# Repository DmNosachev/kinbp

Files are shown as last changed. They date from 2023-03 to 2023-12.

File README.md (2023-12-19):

# KinBP
KinBP is a drop-in replacement controller for [Kinesis Contoured keyboards](https://deskthority.net/wiki/Kinesis_Contoured).

It serves the same purpose as [KinT controller](https://github.com/kinx-project/kint) created by Michael Stapelberg.

KinBP v1.2

## Features and advantages
- Controller with [QMK firmware](https://qmk.fm/) support.
- Uses inexpensive [WeAct Studio STM32F401/STM32F411](https://github.com/WeActTC/MiniSTM32F4x1) MCU board. The cost of manufacturing 5 sets is about 12 USD per controller. The PCB has dimensions less than 100×100 mm. Many manufacturers provide additional discounts for smaller boards.
- Compatible with all Kinesis Contoured keyboards but the earliest models (100/110/120).
- Additional pads for connecting up to 8 swithes (i.e. additional switches on the keyboard or foot pedals).
- Replacement thumb cluster PCBs with reversible design. They may be needed for some of 13x models (see below). 
- Thumb cluster switch mounting plates.

## Changelog
1.21
- added 7-pin 1.25mm connector footprints (micro JST) for custom thumb cluster PCBs
- added spare footprints upside down for connectors with pins on the other sideю

## BOM
###  Connectors
The choice of connectors depends on the keyboard model:
 - KB600 (Advantage2).
 1. 6x 13-pin FPC connectors. [Molex 39-53-2135](https://octopart.com/39-53-2135-molex-7670149?r=sp).  Please note that the cheap (5 USD for 20 pcs) [connectors from Aliexpress](https://aliexpress.com/item/1005001616368875.html?item_id=1005001616368875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) are polarised and can only be used for the top row connectors on the KB600; using them in the other positions will not work because the pads on the FPC cable are on the wrong side and the cables are too short to be twisted.

 - KB500 (Advantage).
 1. Connecting keywells and top rows: 4x 13-pin FPC connectors, same as mentioned above.
 2. Connecting thumb cluster PCBs: 2x 10-pin angled 2.54mm headers.

 - KB13x (Essential, Classic, Professional).
 1. Connecting keywell PCBs: 2x [angled 13-pin FPC connectors](https://aliexpress.com/item/32896882494.html?item_id=32896882494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).
 2. Connecting top rows: same angled connectors or straight (same as for KB500/KB600).
 3. Some models had LEDs on the thumb cluster PCBs instead of the controller PCB. In this case you will need a pair of new thum cluster PCBs, optional switch mounting plates (see below) and set of cables/connectors with 1.25mm pitch: 2x [7 pin micro JST 10cm cables](https://aliexpress.com/item/4000588750065.html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) + 4x [7 pin micro JST angled connector](https://aliexpress.com/item/4000587245338.html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).
 
 Example of incompatible stock thumb cluster PCBc (Kinesis Professional KB134PC): KB134PC controller
 
 You can also reuse connectors from an stock controller, but desoldering them can be tricky. Please note that the Chinese aliexpress connectors and some of the older connectors only had contacts on one side. For the top rows, you need to position the connector so that the contacts are on the outside (there are two footprints for this): top row connector
 
### Controller PCB (/controller-pcb).
  - [WeAct Studio STM32F401 or STM32F411](https://github.com/WeActTC/MiniSTM32F4x1) board. You can buy them for about 6 USD at the [official Aliexpress store](https://weactstudio.aliexpress.com/). Beware of pirated copies!
  KinBP v1.21
  - 4 pcs 3-mm LEDs
  - 4 pcs 0805 or through-hole resistors. Their value depends on the type of LEDs (I use 1.5k Ohm for orange LEDs).
  - Pair of USB Type C male and female connectors.
###  Thumb cluster (/thumb-pcb)
  - The design is reversible. So, a minimal batch of 5 PCBs will give you 2 pairs + 1 spare.
  Thumb PCB
  Thumb PCB
  - 12x SOD-123 1N4148 diodes.
  - Optional [switch mounting plates](https://github.com/DmNosachev/kin80/tree/main/plates/thumb)
  - set of connectors and cables (see above)
### Switches
  - Optional: 68 pcs Cherry MX compatible switches.
  
## Buid guide
1. Test your keyboard. Identify faulty switches. Decide if you like the switches (most of the time there will Cherry Browns) and the top row rubber buttons. If rubber buttons are unacceptable to you and you do not mind spending a lot of time on hand-wiring, then it is worth considering an alternative project — (Kin80)[https://github.com/DmNosachev/kin80].
2. Disassemble the keyboard. Remove all screws and remove all PCBs. If some of the rubber buttons don't work well, the top row assembly can be taken apart and repaired by sticking pieces of copper tape on the button bottoms. Use hot-melt adhesive to asseble it back.
3. Assemble the controller PCB.
4. Optional: assemble thumb cluster PCBs.
5. Case. Seal the holes on the back of the case with pieces of plastic. Glue the USB connector to the back of the case. Optional: use bitumen sound deadening pads to improve acoustics.
6. [Setup the QMK](https://docs.qmk.fm/).
7. Flash the firmware: `qmk flash -kb kinbp -km default`. Hold 'boot0' button on MCU board, press 'reset', then release 'boot0' to enter bootloader.

## TODO
- FR4 mounting plate for the thumb cluster.
- Create universal or separate PCB with RP2040 support.

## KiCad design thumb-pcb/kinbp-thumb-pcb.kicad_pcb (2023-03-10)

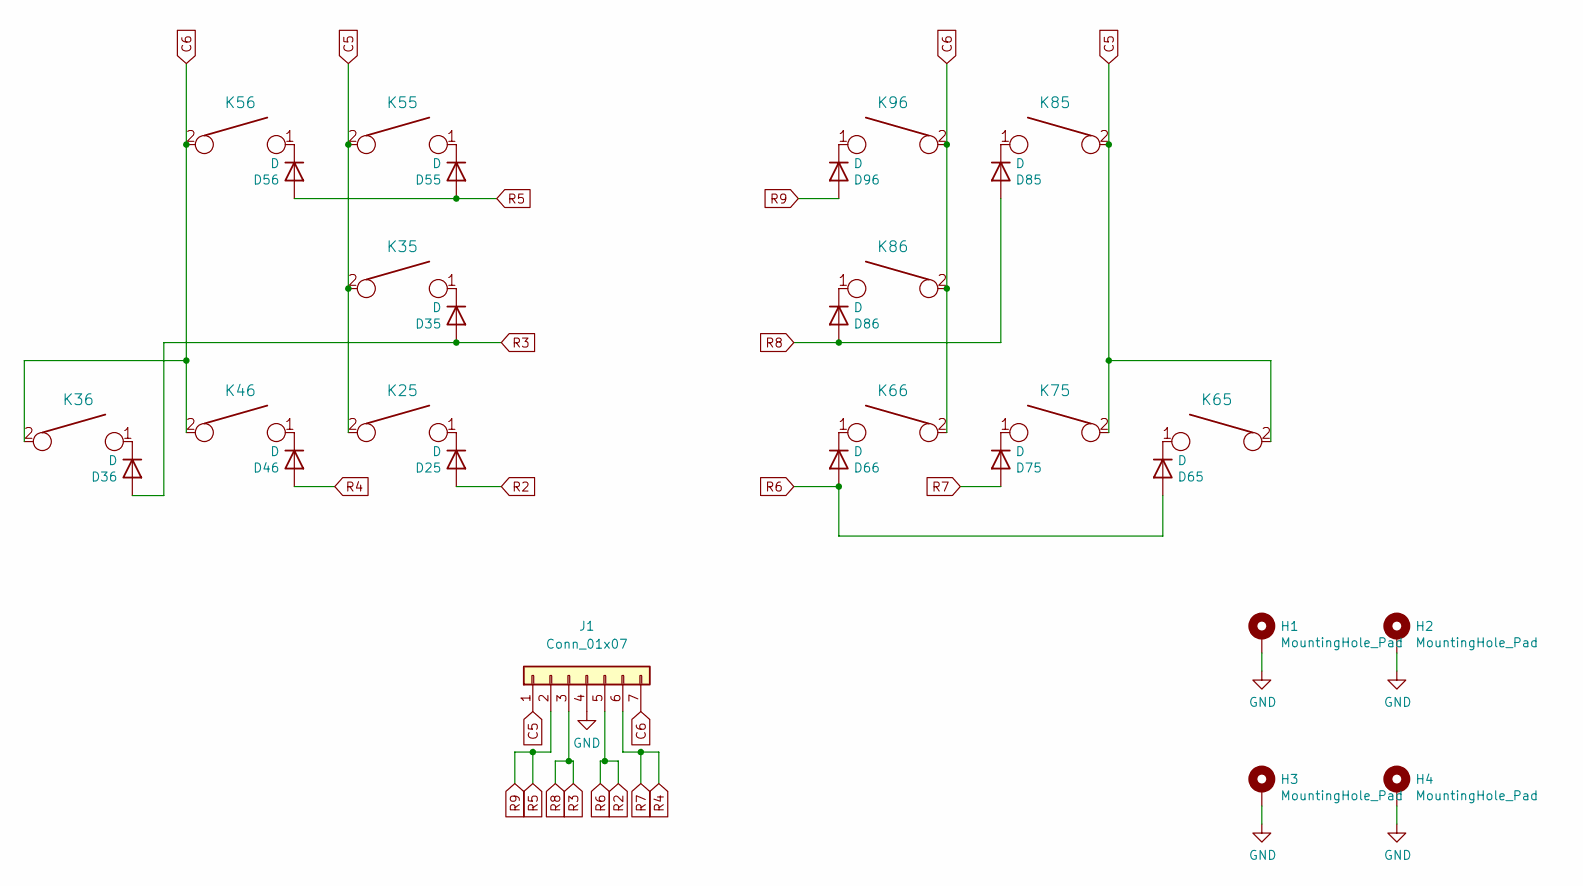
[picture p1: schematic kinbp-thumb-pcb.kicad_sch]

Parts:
D25, D35, D36, D46, D55, D56, D65, D66, D75, D85, D86, D96: D; D_SOD-123
H1, H2, H3, H4: MountingHole_Pad; MountingHole_3.7mm_Pad
J1: Conn_01x07; Molex_PicoBlade_53048-0710_1x07_P1.25mm_Horizontal
K25, K35, K36, K46, K55, K56: KEYSW; MXOnly-1U-NoLED-twin
K65, K66, K75, K85, K86, K96: KEYSW; MXOnly-1U-NoLED

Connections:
C5: J1.1, K25.2, K35.2, K55.2, K65.2, K75.2, K85.2
C6: J1.7, K36.2, K46.2, K56.2, K66.2, K86.2, K96.2
GND: H1.1, H2.1, H3.1, H4.1, J1.4
unnamed: D25.1 (K), K25.1
unnamed: D35.1 (K), K35.1
unnamed: D36.1 (K), K36.1
unnamed: D46.1 (K), K46.1
unnamed: D55.1 (K), K55.1
unnamed: D56.1 (K), K56.1
unnamed: D65.1 (K), K65.1
unnamed: D66.1 (K), K66.1
unnamed: D75.1 (K), K75.1
unnamed: D85.1 (K), K85.1
unnamed: D86.1 (K), K86.1
unnamed: D96.1 (K), K96.1
R2: D25.2 (A), D65.2 (A), D66.2 (A), J1.5
R3: D35.2 (A), D36.2 (A), D85.2 (A), D86.2 (A), J1.3
R4: D46.2 (A), D75.2 (A), J1.6
R5: D55.2 (A), D56.2 (A), D96.2 (A), J1.2

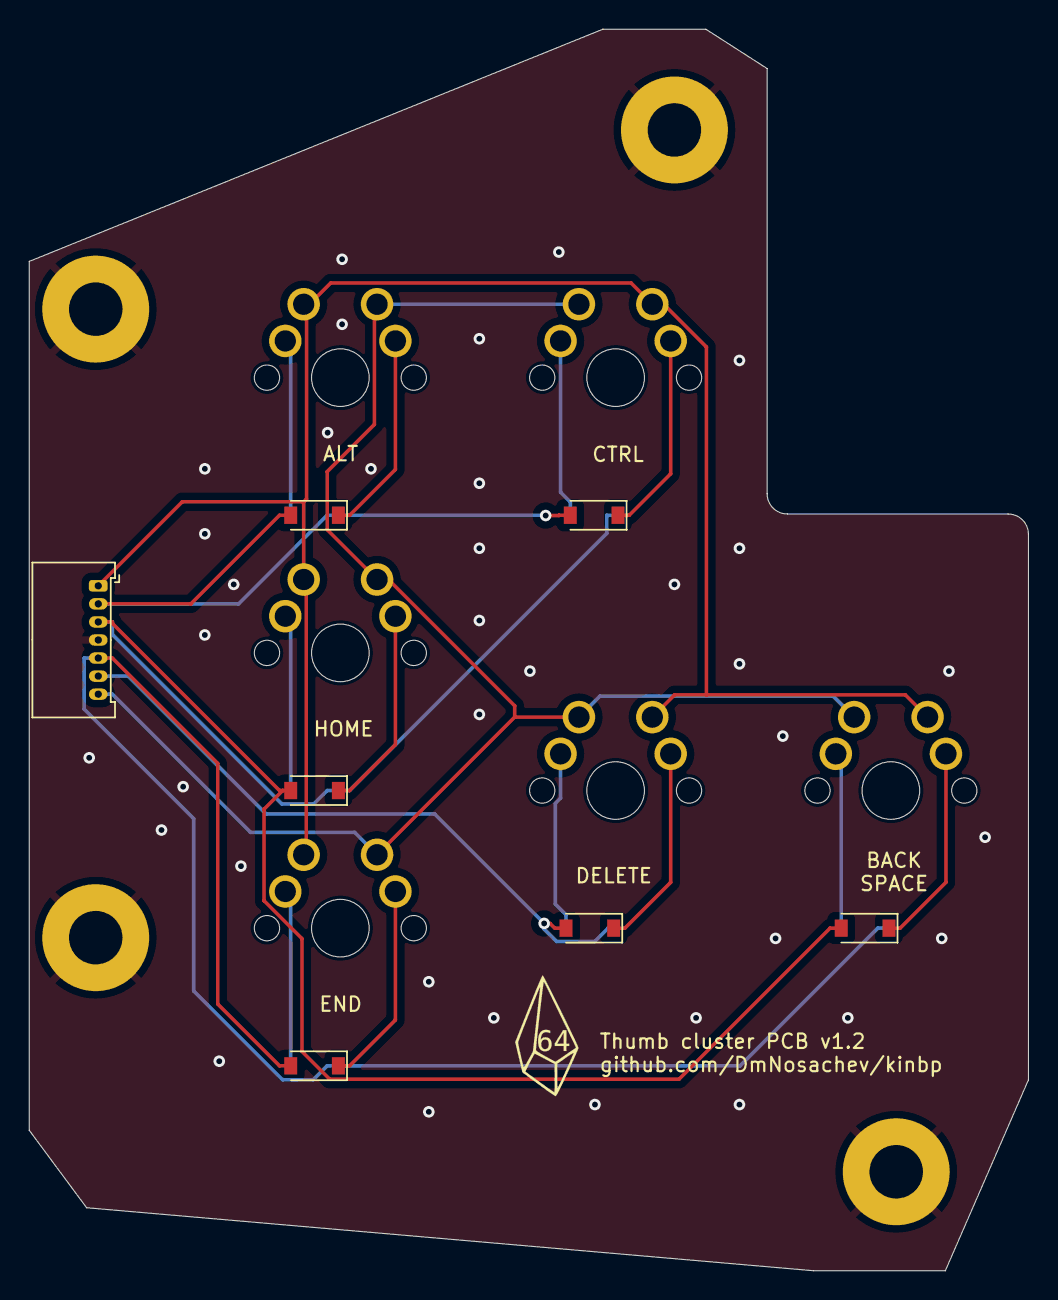
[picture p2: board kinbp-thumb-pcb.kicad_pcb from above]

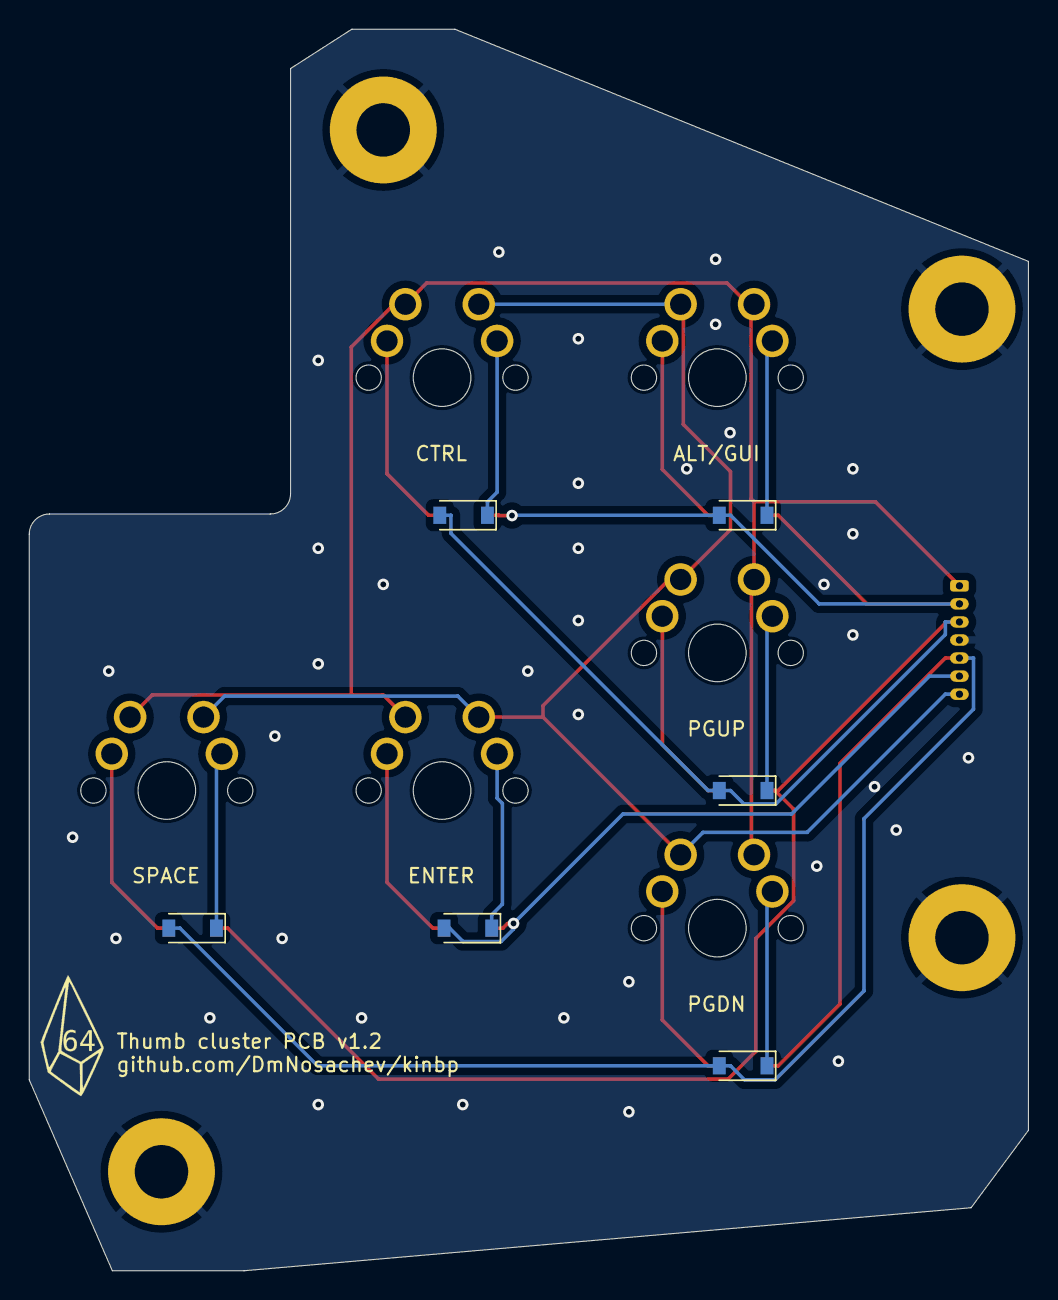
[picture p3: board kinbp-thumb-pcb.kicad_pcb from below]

Board: 2 copper layers, 69.2 x 85.9 mm, 31 parts (13 on the bottom side), 19 nets.

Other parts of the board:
G1, G2: LOGO; q64logo

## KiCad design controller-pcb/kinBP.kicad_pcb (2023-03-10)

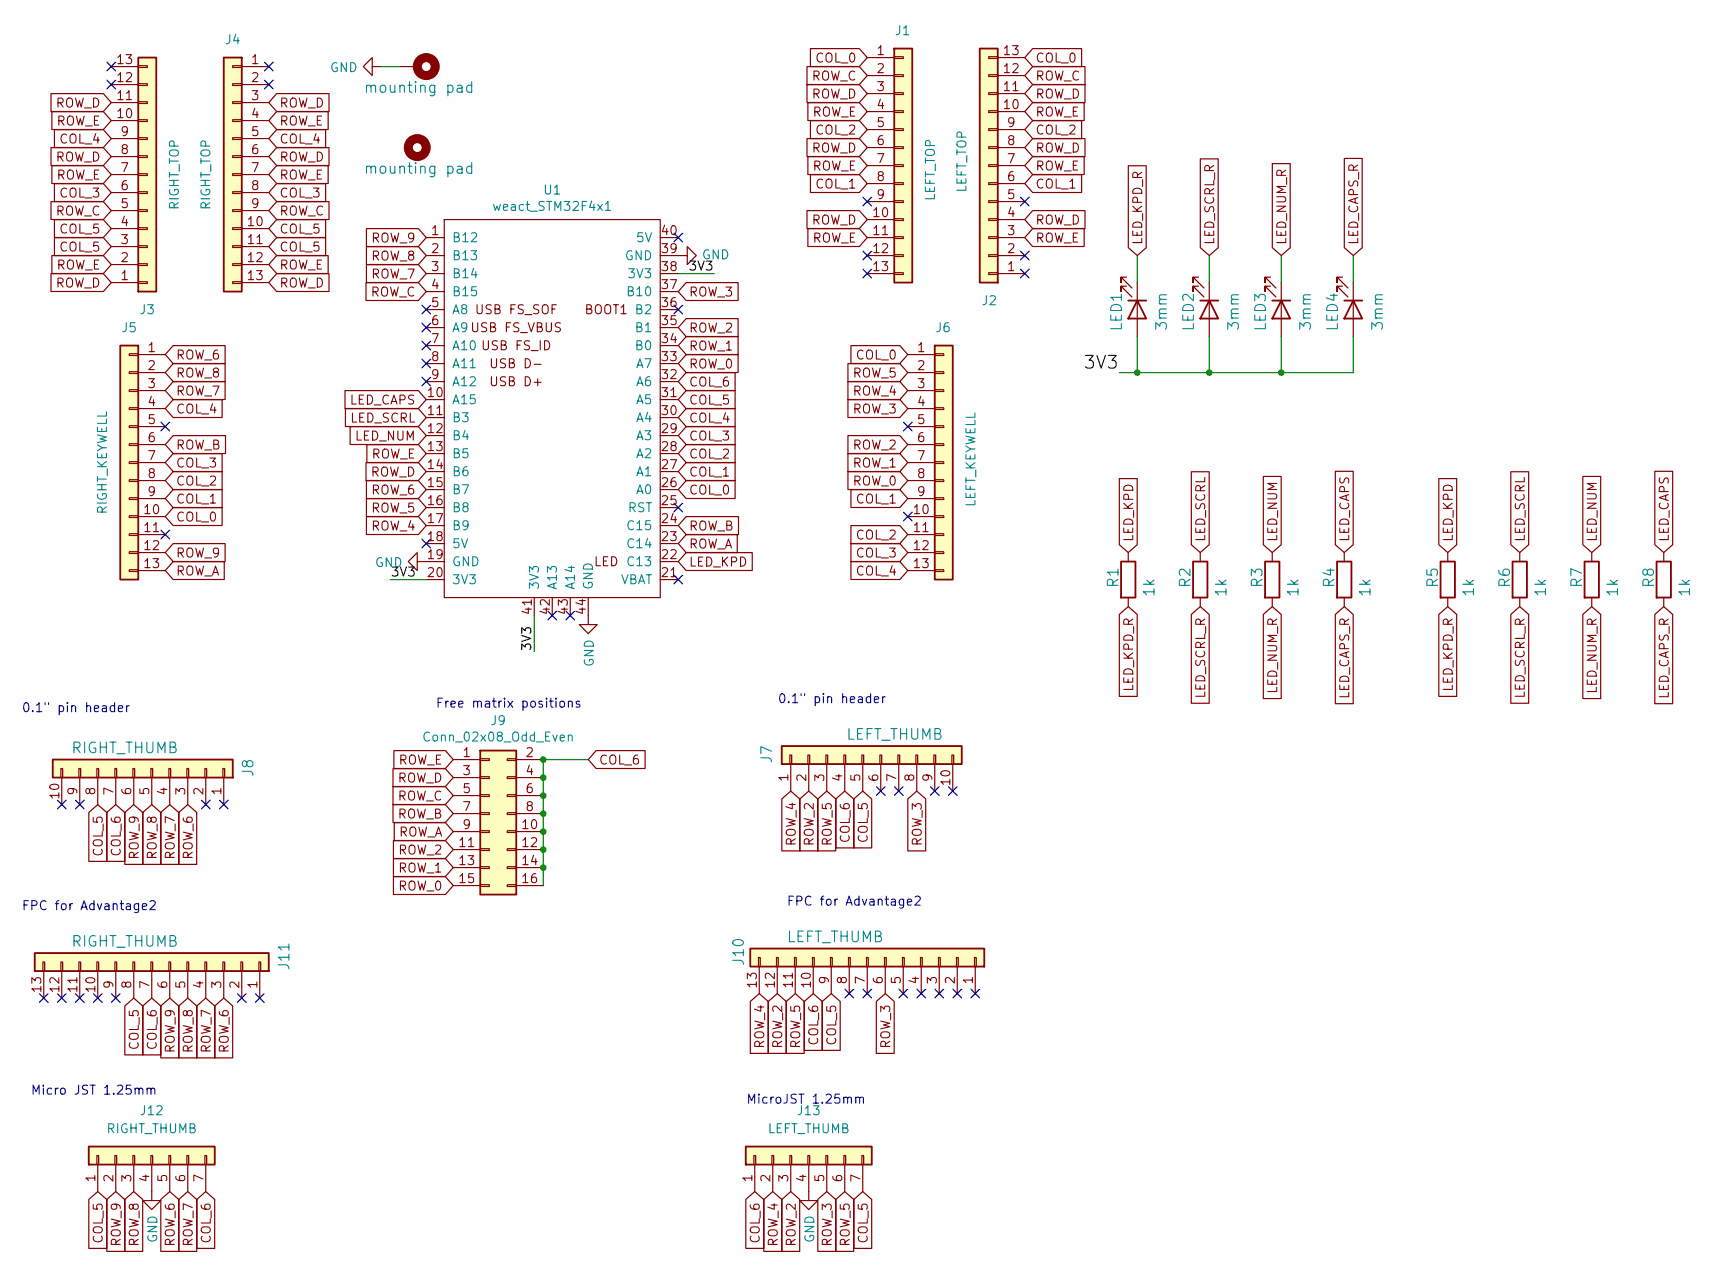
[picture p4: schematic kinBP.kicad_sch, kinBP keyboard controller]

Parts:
H1: mounting pad; MountingHole_4.3mm_M4_Pad
H2: mounting pad; MountingHole_6mm
J1, J2: LEFT_TOP; 39-53-2135
J3, J4: RIGHT_TOP; 39-53-2135
J5: RIGHT_KEYWELL; 39-53-2135
J6: LEFT_KEYWELL; 39-53-2135
J7: LEFT_THUMB; PinHeader_1x10_P2.54mm_Vertical
J8: RIGHT_THUMB; PinHeader_1x10_P2.54mm_Vertical
J9: Conn_02x08_Odd_Even; PinHeader_2x08_P2.54mm_Vertical
J10: LEFT_THUMB; 39-53-2135
J11: RIGHT_THUMB; 39-53-2135
J12: RIGHT_THUMB; Molex_PicoBlade_53048-0710_1x07_P1.25mm_Horizontal
J13: LEFT_THUMB; Molex_PicoBlade_53048-0710_1x07_P1.25mm_Horizontal
LED1, LED2, LED3, LED4: 3mm; LED_D3.0mm
R1, R2, R3, R4: 1k; R_0805_2012Metric_Pad1.20x1.40mm_HandSolder
R5, R6, R7, R8: 1k; R_Axial_DIN0207_L6.3mm_D2.5mm_P7.62mm_Horizontal
U1: weact_STM32F4x1; STM32F4x1_MiniF4

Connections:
/3V3: LED1.2 (A), LED2.2 (A), LED3.2 (A), LED4.2 (A), U1.20 (3V3), U1.38 (3V3), U1.41 (3V3)
COL_0: J1.1, J2.13, J5.10, J6.1, U1.26 (A0)
COL_1: J1.8, J2.6, J5.9, J6.9, U1.27 (A1)
COL_2: J1.5, J2.9, J5.8, J6.11, U1.28 (A2)
COL_3: J3.6, J4.8, J5.7, J6.12, U1.29 (A3)
COL_4: J3.9, J4.5, J5.4, J6.13, U1.30 (A4)
COL_5: J3.3, J3.4, J4.10, J4.11, J7.5, J8.8, J10.9, J11.8, J12.1, J13.7, U1.31 (A5)
COL_6: J7.4, J8.7, J9.2, J9.4, J9.6, J9.8, J9.10, J9.12, J9.14, J9.16, J10.10, J11.7, J12.7, J13.1, U1.32 (A6)
GND: H1.1, J12.4, J13.4, U1.19 (GND), U1.39 (GND), U1.44 (GND)
LED_CAPS: R4.1, R8.1, U1.10 (A15)
LED_CAPS_R: LED4.1 (K), R4.2, R8.2
LED_KPD: R1.1, R5.1, U1.22 (C13)
LED_KPD_R: LED1.1 (K), R1.2, R5.2
LED_NUM: R3.1, R7.1, U1.12 (B4)
LED_NUM_R: LED3.1 (K), R3.2, R7.2
LED_SCRL: R2.1, R6.1, U1.11 (B3)
LED_SCRL_R: LED2.1 (K), R2.2, R6.2
ROW_0: J6.8, J9.15, U1.33 (A7)
ROW_1: J6.7, J9.13, U1.34 (B0)
ROW_2: J6.6, J7.2, J9.11, J10.12, J13.3, U1.35 (B1)
ROW_3: J6.4, J7.8, J10.6, J13.5, U1.37 (B10)
ROW_4: J6.3, J7.1, J10.13, J13.2, U1.17 (B9)
ROW_5: J6.2, J7.3, J10.11, J13.6, U1.16 (B8)
ROW_6: J5.1, J8.3, J11.3, J12.5, U1.15 (B7)
ROW_7: J5.3, J8.4, J11.4, J12.6, U1.3 (B14)
ROW_8: J5.2, J8.5, J11.5, J12.3, U1.2 (B13)
ROW_9: J5.12, J8.6, J11.6, J12.2, U1.1 (B12)
ROW_A: J5.13, J9.9, U1.23 (C14)
ROW_B: J5.6, J9.7, U1.24 (C15)
ROW_C: J1.2, J2.12, J3.5, J4.9, J9.5, U1.4 (B15)
ROW_D: J1.3, J1.6, J1.10, J2.4, J2.8, J2.11, J3.1, J3.8, J3.11, J4.3, J4.6, J4.13, J9.3, U1.14 (B6)
ROW_E: J1.4, J1.7, J1.11, J2.3, J2.7, J2.10, J3.2, J3.7, J3.10, J4.4, J4.7, J4.12, J9.1, U1.13 (B5)

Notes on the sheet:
FPC for Advantage2
0.1" pin header
MicroJST 1.25mm
Micro JST 1.25mm
Free matrix positions

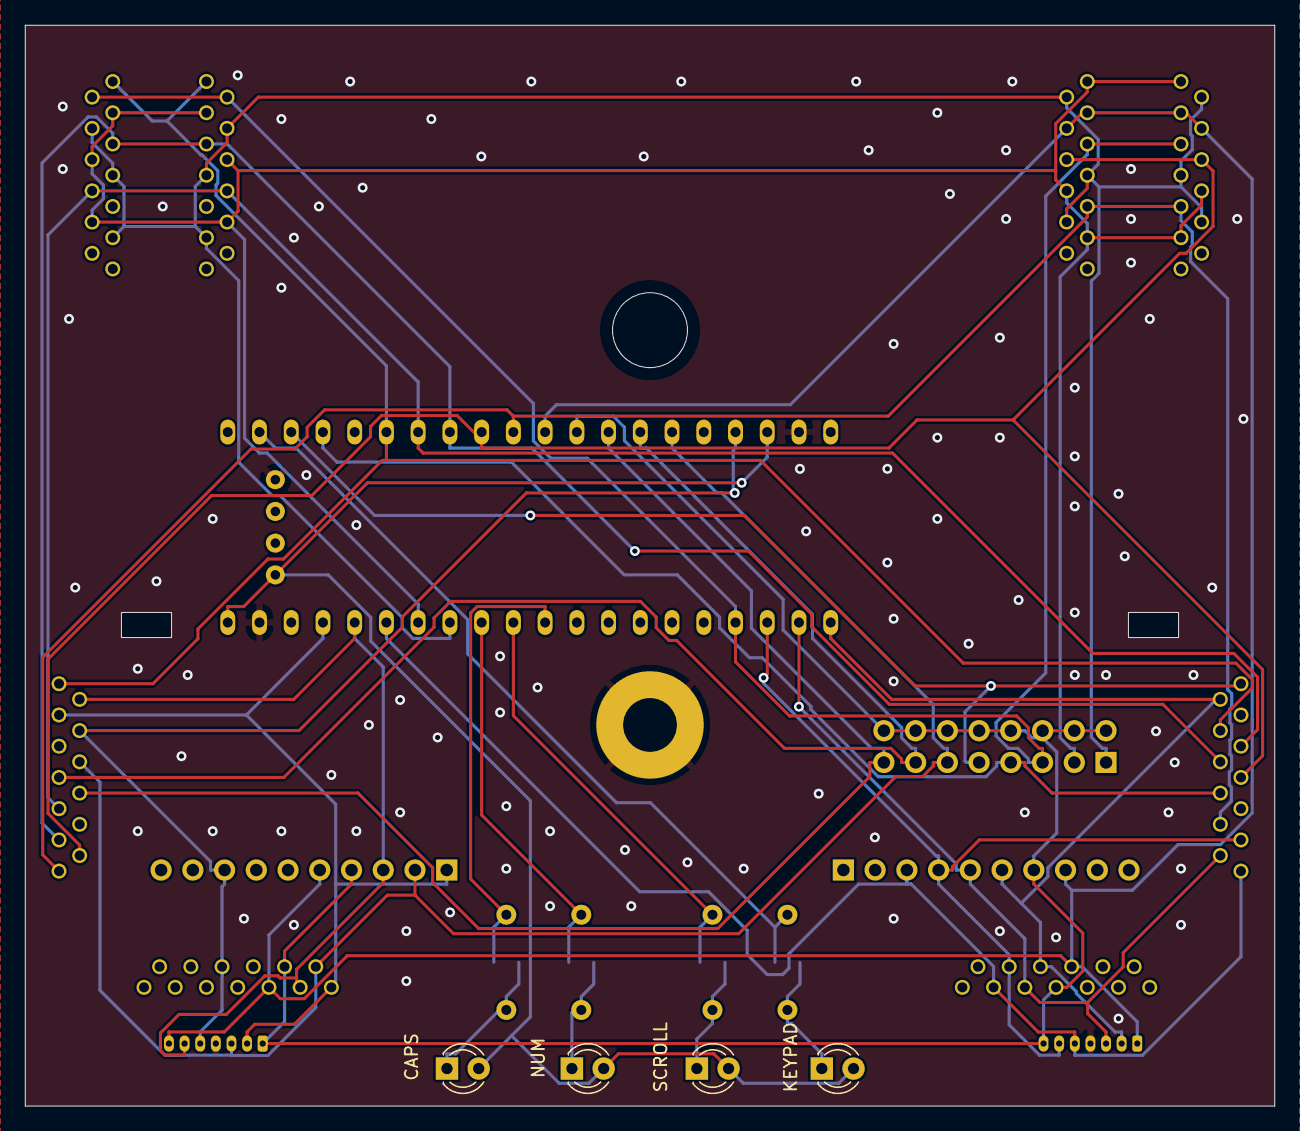
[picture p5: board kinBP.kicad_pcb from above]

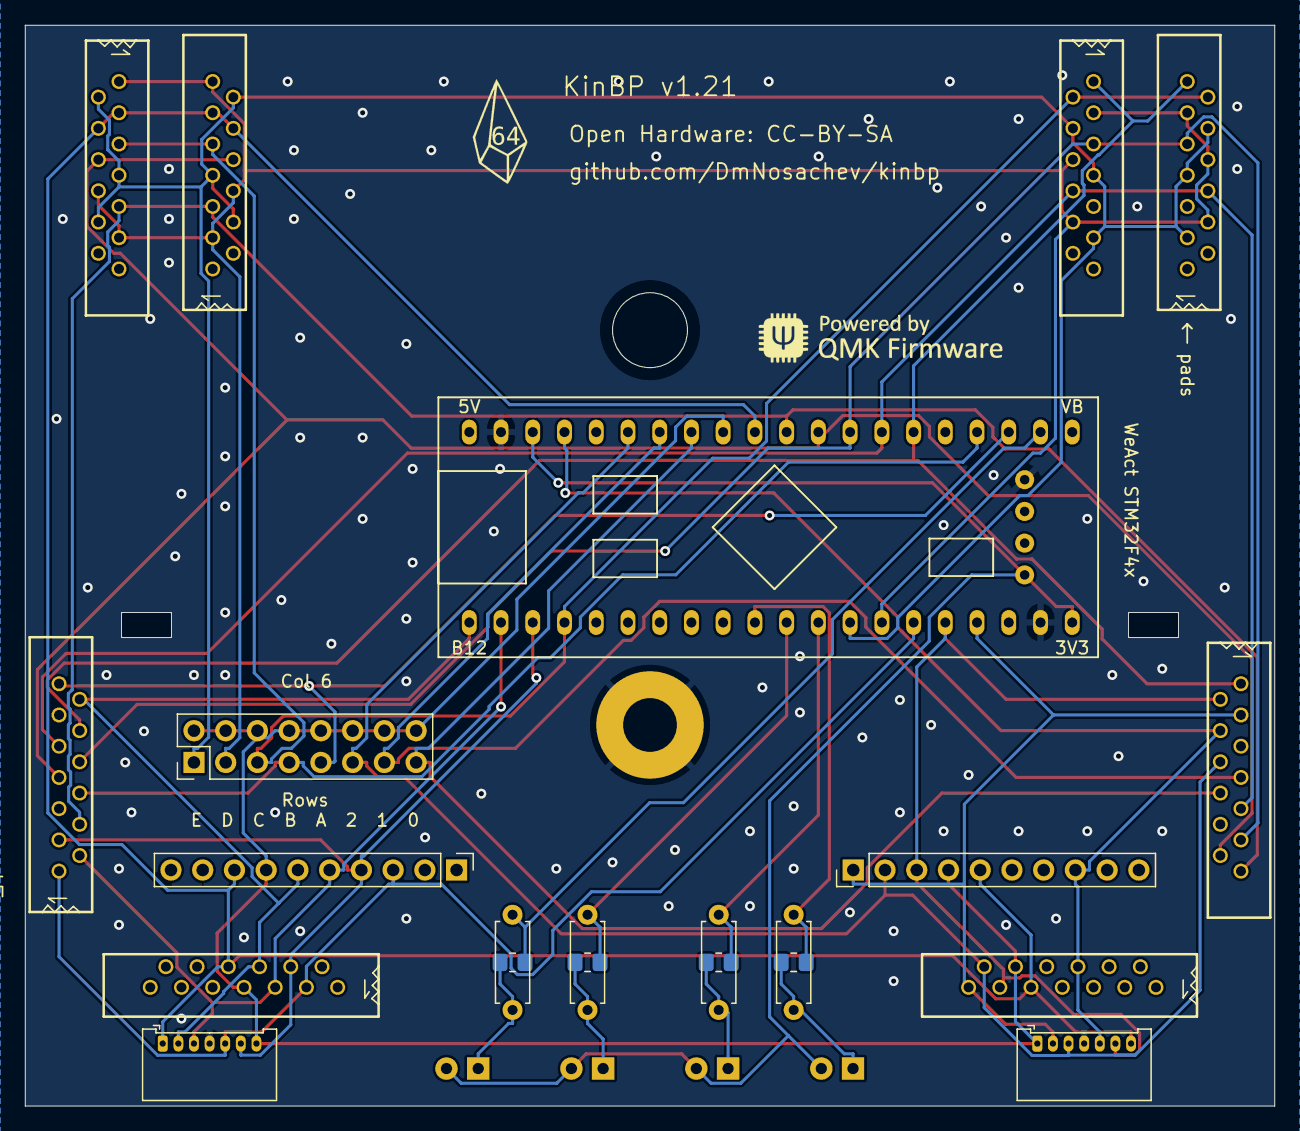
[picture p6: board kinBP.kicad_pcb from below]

Board: 2 copper layers, 100.0 x 86.5 mm, 29 parts (23 on the bottom side), 32 nets.

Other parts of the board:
G1: LOGO; q64logo

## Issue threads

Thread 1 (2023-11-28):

How to use the additional 8 pads?

afonsoguerra, 2023-11-28:
Hi,
Thanks for this project!
I’ve now built a kintwin board (derived from this project), which I’m happily using on a KB600. I would now like to make the most of it and use the extra pads, ideally to put the kinesis triple pedal with the original cable back, and/or add a rotary encoder.

Do you have any pointers on the best way to modify the firmware to access these pins? The hardware side seems easy enough to me, but I don’t see any clear space in the layout to edit the mappings for these, and I’m not well versed enough in the innards of QMK to know if I’m missing something obvious or where to modify things to add these.

DmNosachev, 2023-12-02:
Hi,
I apologize that the answer took a long time. I completed the documentation and changed the firmware in accordance with modern QMK requirements.
It's temporarily located in my fork: https://github.com/DmNosachev/qmk_firmware/tree/kinbp/keyboards/kinesis/kinbp
Today I'm going to create a pull request to the main QMK repository.

afonsoguerra, 2023-12-02:
Many thanks! Much appreciated. Perfectly on time :) I'll have a go and if it all works out I'll just close this issue in the next few days.

LeoMegaAir, 2024-02-17:
Hi Dmitry, thank you so much for your project!
I was thinking about qmk but the lack of the extra buttons was a deal breaker for me (see pics), so your 8 additional switches were exactly what I was dreaming of.

I kind of can solder but don't understand much in this so my apologies if my question would sound stupid: aren't we supposed to have diodes somewhere there here? Are they not needed or should one still add them them to the extra buttons?

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

DmNosachev, 2024-02-21:
Hello. Sorry for the delay in response, I'm on vacation. It is advisable to add diodes to avoid possible ghosting when pressing several keys simultaneously.
The direction of the diodes is 'COL2ROW', i.e. you need to connect the diode in such a way that the current flows from column to row. For example, solder one switch lead directly to the column, and the second to the row via a diode, with the anode to the switch

LeoMegaAir, 2024-02-21:
Aha, I knew it! We do need diodes!
Would you be able to change the PCB for these diodes to be put directly there? I wouldn't be asking if I could figure it out myself. Obviously if and when you have time.

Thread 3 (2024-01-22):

Blue Pill

anm, 2024-01-22:
I would like to make the blue pill version but cannot find the design files. Please can you publish or direct me to it.

DmNosachev, 2024-01-23:
Hi,
KiCAD sources are in [controller-pcb](https://github.com/DmNosachev/kinbp/tree/main/controller-pcb) directory.

I would only recommend using Blue Pill boards if you have old stock or Type C version made by WeACT Studio. As far as I remember, genuine F103 MCUs from STM have long been rare, and I can’t say anything about the level of compatibility of Chinese clones.

anm, 2024-01-24:
Sorry, I still don't see it, in the directory, or in the history.

DmNosachev, 2024-01-25:
They're definitely here. I thought that the problem was in the privacy settings of the repository, but everything is available without a login.
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

anm, 2024-01-25:
I see these files, but they are for the black pill version.

DmNosachev, 2024-01-25:
Then I apologize, I misunderstood you. Once upon a time, the very first version of the board (before publication on Github) was for WeAct Blue Pill (not those classic generic Blue Pill), but I quickly discovered that they were becoming EOL, and the board had several other problems.
I have plans to update the project: add a second rotated footprint for the tumb cluster connectors and add support for RP2040 (second offset footprint). I just have to find time for this.

anm, 2024-01-25:
I just checked again I was not confused with another project. It is described here: https://deskthority.net/viewtopic.php?t=25032 - v1.1 of this project it looks like.

I believe the pinouts are different. Maybe the WeAct ones are not, but at least some of them are.

anm, 2024-01-25:
I was looking for that one because I have some blue pills with different pinout, but I can just make my own.

DmNosachev, 2024-01-25:
I remembered. WeAct Blue Pill seemed to be almost identical to WeAct Black Pill, with few exceptions (see the table below).

I can upload the archive with version 1.1 somewhere, but, unfortunately, I’m bad with documentation - either there is practically none, or it’s a complete mess. So now I don’t remember what exactly version 1.1 is compatible with; you’ll have to look into the board’s source code yourself. Perhaps it will be much easier to take the latest sources and remake them to suit your needs.
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

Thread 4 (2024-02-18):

Hooking up a speaker?

LeoMegaAir, 2024-02-18:
I know you invested quite an effort to make your keyboard silent so my question will sound weird but is there a way to add a speaker to your setup, and how?

The Kinesis Contoured built-in speaker helps avoid bottoming the switch out at key press, plus it can be good to know if you really got the button pressed because the PC does not react instantly (when hitting one of those rubber buttons, e.g. F5 while reloading a web page).

afonsoguerra, 2024-02-19:
I'm not the dev here, but just came across this and just to point out the software that runs on the kintbp/kintwin/kint41 etc, is QMK, so you might get more luck getting help there. To get you started, here is their documentation for audio: https://github.com/qmk/qmk_firmware/blob/master/docs/feature_audio.md

From the hardware side, you just need to find a spare pin for it, it will mostly be software programming I think.

LeoMegaAir, 2024-02-20:
> I'm not the dev here, but just came across this and just to point out the software that runs on the kintbp/kintwin/kint41 etc, is QMK, so you might get more luck getting help there.

This (**kinbp**) project supports QMK firmware. Question is, how to alter the PCB files to get two holes for the speaker in it and how to change/add the firmware get the keyboard produce the sounds similar to what Kinesis makes with the sound on, i.e. clicks on button presses.

DmNosachev, 2024-02-21:
HI. I'll be back from vacation next week and will be able to see the current state of audio support in QMK for STM32 MCUs.
You will need to install KiCAD to modify the PCB.

anm, 2024-03-02:
I would like to do this too. It looks like the only spare usable pin is PB2/BOOT1 which has no timer output. The LED pins have some timers though that might suit for sound, so might move an LED to PB2.

I don't have the firmware at all though. It looks like the keyboard files are not in the qmk distribution and I can't find them here.

anm, 2024-03-07:
I have designed a board with a piezo using two drive pins (one for each side). A one pin driver seems to exist for the STM32F4s, but I'm not sure the ALT_PIN stuff is implemented for the other pin, so maybe only one usable unless that is improved. I'll let you know if it works.

anm, 2024-04-04:
I have it working. I moved some stuff on the board though - should probably test v2 before publishing.

anm, 2024-07-08:
Tested and working: https://github.com/anm/kinesis_controller

The software needs some work though. The hardware PWM driver doesn't work properly, so switched to software which is ok, but not got the clicky working well yet. Generally need to rearrage the config stuff too - it's mostly just in the F411 directory, not F401.

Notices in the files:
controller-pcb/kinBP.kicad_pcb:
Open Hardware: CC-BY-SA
